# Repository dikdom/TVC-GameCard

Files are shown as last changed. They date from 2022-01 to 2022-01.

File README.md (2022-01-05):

# TVC-GameCard
Egy IO bővítőkártya a Videoton TV Computerhez, melyen 2 extra joy port és egy SN76489 hangchip található. Ez a kártya a TVC játékos lehetőségeit
bővíti a jobb zenei lehetőségeivel és a 4 játékos üzemmóddal.

Ez a repo a méltán nagysikerű Videoton TV Computerhez készített TVC-GameCard IO kártya leírását és újragyártásához szükséges file-okat tartalmazza.
A kártya 2 extra joy portot, egy SN76489 hangchipet (+3 hangcsatorna +1 zajcsatorna) és 4 extra játékot tartalmaz. Bekapcsoláskor a felhasználó
választhat a játékok közül, de akár tovább is léphet a sima, sztenderd BASIC bekapcsolási képernyőre (...khm... felé, mert ha van több IO kártya
is bedugva a gépbe, akkor simán lehet, hogy a következő kártya fogja megfogni a boot folyamatát..)

Könyvtárstruktúra:
- `doc` dokumentumok a kártyáról
- `src`
  - `menu`
    a boot menü forráskódja, ami az ASM80.com oldalon található IDE-vel készült
  - `gal`
    a GAL20V8B chip kódjainak a forrásai, amit a WinCUPL programmal lehet lefordítani
  - `hw` kapcsolási rajz és board layout EagleCAD formátumban
  - `tvc4snake` a TVC4Snake játék forrása
- `bin`
  minden, ami egy kártya elkészítéséhez szükséges: a gerber file csomagok (TH és SMD konfiguráció, az SMD -hez a gyártási file-ok is a JLC felé), 
  a GAL-ok lefordított .jed file-jai és a EPROM-ba írható bináris, ami a lefordított  boot menüt és a játékokat is tartalmazza

MIT License: minden használható/módosítható, de forrást tessék feltüntetni

An IO expander card for Videoton TV Computer having +2 joy port and an SN76489 sound chip.

MIT License: you can use anything as you want but please, link the source in your project

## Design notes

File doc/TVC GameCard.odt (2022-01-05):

TVC GameCard

Felhasználóknak és programozóknak

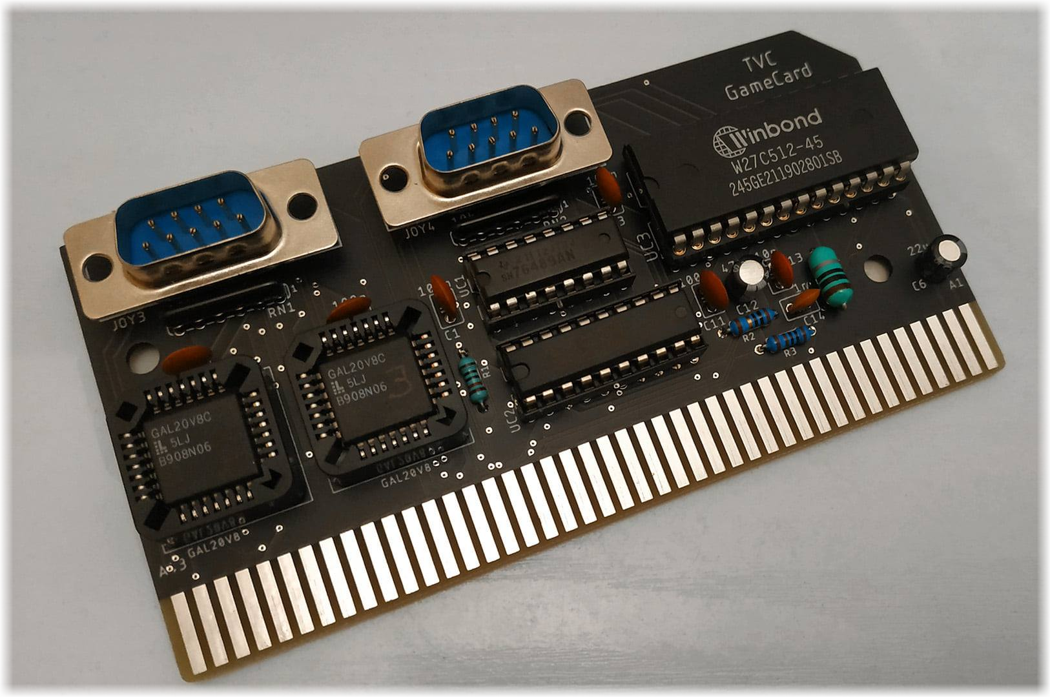
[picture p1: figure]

TVC GameCard - bevezető

A TVC-GameCard a Videoton TV Computer-hez készült IO bővítőkártya. Használatával lehetőségünk van 4 játékos üzemmódú, 3 csatornás zenével rendelkező játékokkal játszani a TVC-n (aminek ugye alapból 2 joy portja van, 1 csatornás hangképzése és alapból nem indul el játék róla).

Megj.:a felhasználók nagyobb részének az SMD alkatrészekkel szerelt kártya jutott, ami nem pont így néz ki, mint ami a fotón látható, de funkciójában a két kiépítés semmiben nem különbözik egymástól.

Használata

Bekapcsolás

A GameCard -ot mindig kikapcsolt TVC -be dugjuk be. Ha lehet, akkor joy kábeleket is a TVC kikapcsolt állapotában csatlakoztassuk. Ha nem lehet, akkor viszont járjunk el kellő körültekintéssel csatlakoztatáskor!

A gép bekapcsolásakor egy egyszerű bootmenü jelenik meg, ahol láthatjuk a játékprogramok szerzőit, a boot menü verzióját és a lehetőségeinket, hogy hogyan haladhatunk tovább.

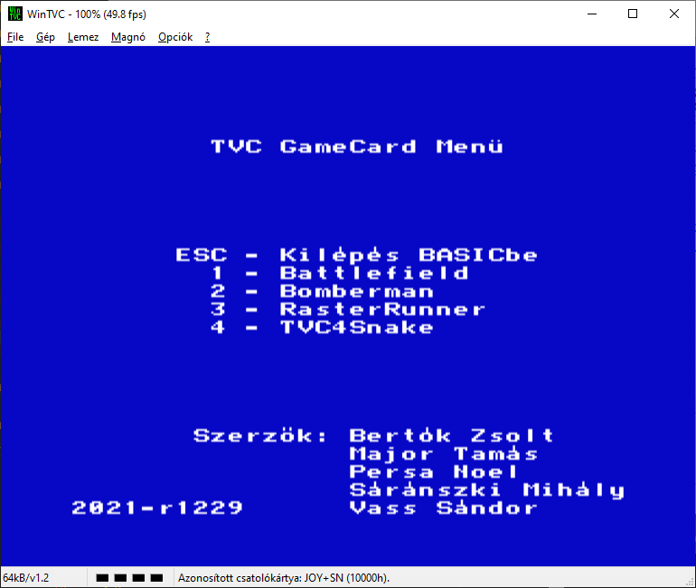
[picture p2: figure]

(WinTVC, v1.3)

Opciók

ESC

A GameCard ilyenkor kilép a menüből és visszaadja a vezérlést a TVC -nek. A TVC befejezi a csatlakoztatott IO kártyák (ha van) INIT rutinjainak a hívásait és aszerint halad tovább. Ha nincs más kártya csatlakoztatva a gépbe, akkor a TVC a szivárványos boot screen-en keresztül eljut a BASIC promptig. Fontos tudni, hogy a GameCard funkciói ekkor is elérhetőek maradnak: az ilyenkor betöltött programok is elérik a +2 joy portot és tudják használni a kártyán található SN76489 hangchipet.

Az EPROM tartalmát is, csak hát azzal ugye nem biztos, hogy sokra mennek…

1-4

A fenti számok egyikével választhatjuk ki, hogy melyik játékkal szeretnénk játszani. Mind a 4 játék támogatja a 4 játékos üzemmódot és egytől egyik kiváló játékokról van szó!!

- A BattleField egy tankos, lövöldözős játék. Lehetőség van négyen, vagy kevesebben és akár gépi ellenfelek ellen is játszani. Többféle pálya közül választhatunk, a repülő a bombáival meg tud viccelni.
- A Bomberman a hagyományos bomberman játék. A kártyán található v1.1 -es változat még nem tartalmaz gépi ellenfeleket viszont többféle játékmenet és többféle pálya közül lehet választani.
- A Rasterrunner egy tron-szerű játék, szintén lehet 4-en vagy kevesebben, akár gépi ellenfelek ellen lehet benne játszani.
- A TVC4Snake játékot szerénységem követte el. 1-4 szereplős, sima, egyszerű kukacjáték annyi csavarral, hogy alkalmanként egy gépi ellenfél (ellenkukac) nehezíti meg a pontszerzést. A játék különlegessége, hogy C nyelven íródott.

RESET

A kártya induláskor átkonfigurálja a reset állapotot, így ha játék közben reset gombot nyomunk, akkor a gép ‘hideg’ resetet hajt végre és a menübe térünk vissza.

Erre azért van szükség, mert amikor a kártyáról indulnak a programok, a BASIC init nem hajtódik végre ezért veszélyes lenne BASIC-be ‘visszatérni’ a játékokból.

Programozóknak

ID string

A kártya az ‘JOY+SN’ ID stringgel rendelkezik, azaz az IO kártyáknak lefoglalt megfelelő RAM területen (0x40-0x6F, 0x70-0x9F, …) a

0x06 0x46 0x4F 0x59 0x2B 0x53 0x4E

byte-ok sorakoznak, amennyiben a TVC érzékelte a kártyát. Egy program így tudja megtalálni, hogy melyik slotban van a TVC-GameCard, amivel együtt az is megvan, hogy a GameCard melyik IO tartományt használja (rendre: 0x10-0x1F, 0x20-0x2F, …)

Control IO regiszter

Az IO kártya a saját foglalatának megfelelő IO tartományt az előző fejezetben megtaláltuk. Miért fontos ez? Azért, mert a kártya ezen IO tartományon belüli portokon keresztül vezérelhető. A +0x0F címen (azaz 0x1F vagy 0x2F, stb, használt slottól függően) a kártya control regisztere található. Ez a regiszter csak írható, olvasásra nincs definiált válasz.

ROM select

A control regiszter alsó 3 bitje (b2-b0) jelöli ki, hogy melyik 8kB-os tartomány legyen látható az EPROM-ból az IO kártyáknak fenntartott EXROM memóriaterületen a TVC számára. Ezt az alsó 3 bitet tipikusan a menü használja, amikor az EPROM-ból másolja be a kiválasztott programot a TVC RAM területére (azaz program indításakor).

SND enable

A control regiszter 4. bitje (b3) engedélyezi, vagy éppenséggel tiltja a hangchipet. A háttérben a hangchiphez tartozó clock jelet tiltja a kártya, így amíg a hangchip le van tiltva, utasítások sem küldhetőek rá (hangerő, első hangjegy beállítása, stb…).

Kezdetek

Induláskor és reset hatására a control regiszterbe a xxxx0111 érték íródik, azaz a 64kB-os EPROMból a legfelső 8kB-nyi terület lapozódik be a TVC EXROM területére (az EEPROM-on a $E000-$FFFF terület a TVC $C000-$DFFF területére). A TVC-GameCard -on itt található a boot menü program.

SN regiszter

Az SN chip regisztere a +0x00 címen található. Ez a regiszter is csak írható. Fontos tudni, hogy az TVC GameCard -on az SN chip a TVC órajelét kapja (3,125MHz), mint alapórajel, azaz ez nem egyezik meg a Multichip soundcard -on található SN chip órajelével (3,579MHz). A két órajel között kb. egy ⅞ -os szorzó van (MC clock * 7 / 8 = GC clock)

Joystick portok

A két extra joystick állapotait a +0x02 és a +0x03 portok olvasásával szerezhetjük meg. A bitek alacsonyaktívak (azaz a bit 0 értéke jelenti az aktivitást) és a következő hozzárendeléssel rendelkeznek:

- bit0: fölfelé irány
- bit1: lefelé irány
- bit2: balra irány
- bit3: jobbra irány
- bit4: tűzgomb
- b5-b7: nem definiált

A két extra joy port nem rendelkezik a TVC joystick-ok második tűzgombjával, viszont autofire-barát, azaz a +5V ki van vezetve.

Például egy

- alaphelyzetben lévő joy port a következő értéket kell visszaadja:

beolvasott_érték AND b00011111 => b00011111

- egy tűzgombot lenyomott joy esetében:

beolvasott_érték AND b00011111 => b00001111

- egy fölfelé és jobbra, átlósan húzott joy esetében:

beolvasott_érték AND b00011111 => b00010110

Gyakorlatilag ennyi. Aki ezt tudja, innentől tudja programozni a GameCard -ot, tud rá játékot is írni.

Források

Minden más megtalálható a kártya github lapján: https://github.com/dikdom/TVC-GameCard

Köszönet

Köszönettel tartozom a programozóknak, akiknek a játékai nélkül nem jöhetett volna létre ez a projekt. ABC rendben:

- Bertók Zsolt
- Major Tamás
- Persa Noel
- Sáránszki Mihály

Nagyon szép, nagyon jó ez a kártya, viszont a szuper játékok nélkül fabatkát sem ér.

Sáránszki Mihálynak köszönet jár ismét a remek cÍmlap fotóért.

És köszönettel tartozom a családomnak is, különösképpen a feleségemnek, aki eltűri, hogy el-eltűnök a családi életből 1-2, néha több órára az ilyen projektjeim végett…

Vass Sándor

Budapest, 2022, Január 5.

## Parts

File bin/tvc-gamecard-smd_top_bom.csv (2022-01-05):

Comment | Designator | Footprint | LCSC Part #
1k | R3 | R0805 | C17513
1n | C14 | C0805 | C46653
10R | R2 | R0805 | C17415
10k | R1 | R0805 | C17414
10n | C13 | C0805 | C1710
10uH | L1 | L1210 | C1051
22u | C6 | C0805 | C45783
47u | C12 | C1206 | C96123
74HCT574D | UC2 | SO20W
100n | C1 C3 C4 C5 C11 | C0805 | C49678
CTS742C083 | RN1 RN2 RN3 | 0603_x4 | C29718

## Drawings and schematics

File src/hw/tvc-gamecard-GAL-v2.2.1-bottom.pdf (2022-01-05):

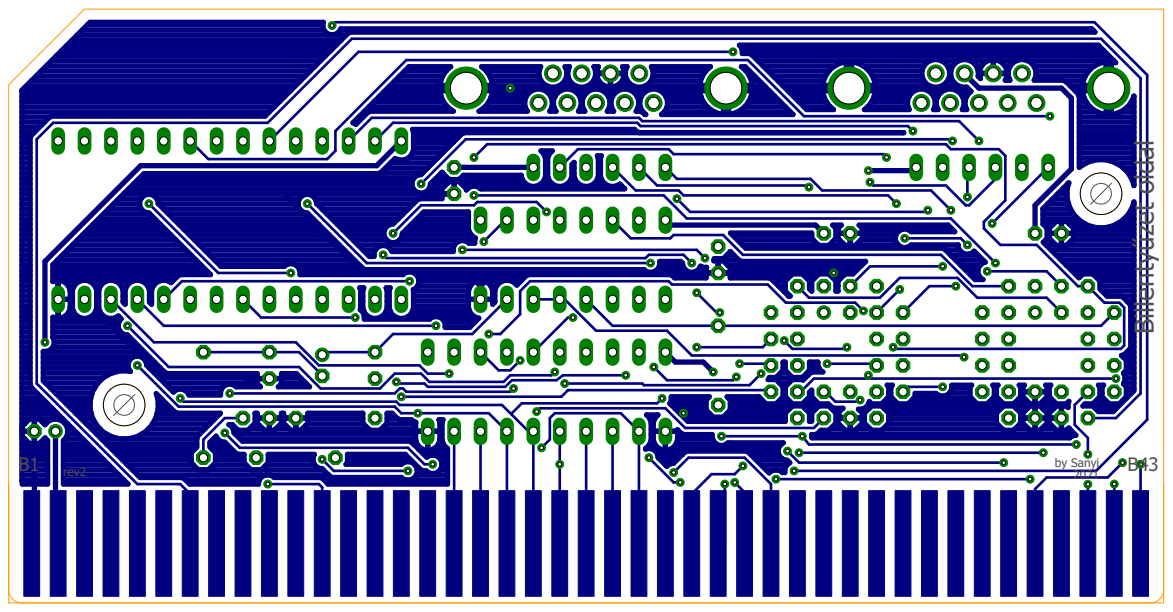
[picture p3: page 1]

Billentyűzet oldal by Sanyi 2021 B1 rev2 B43

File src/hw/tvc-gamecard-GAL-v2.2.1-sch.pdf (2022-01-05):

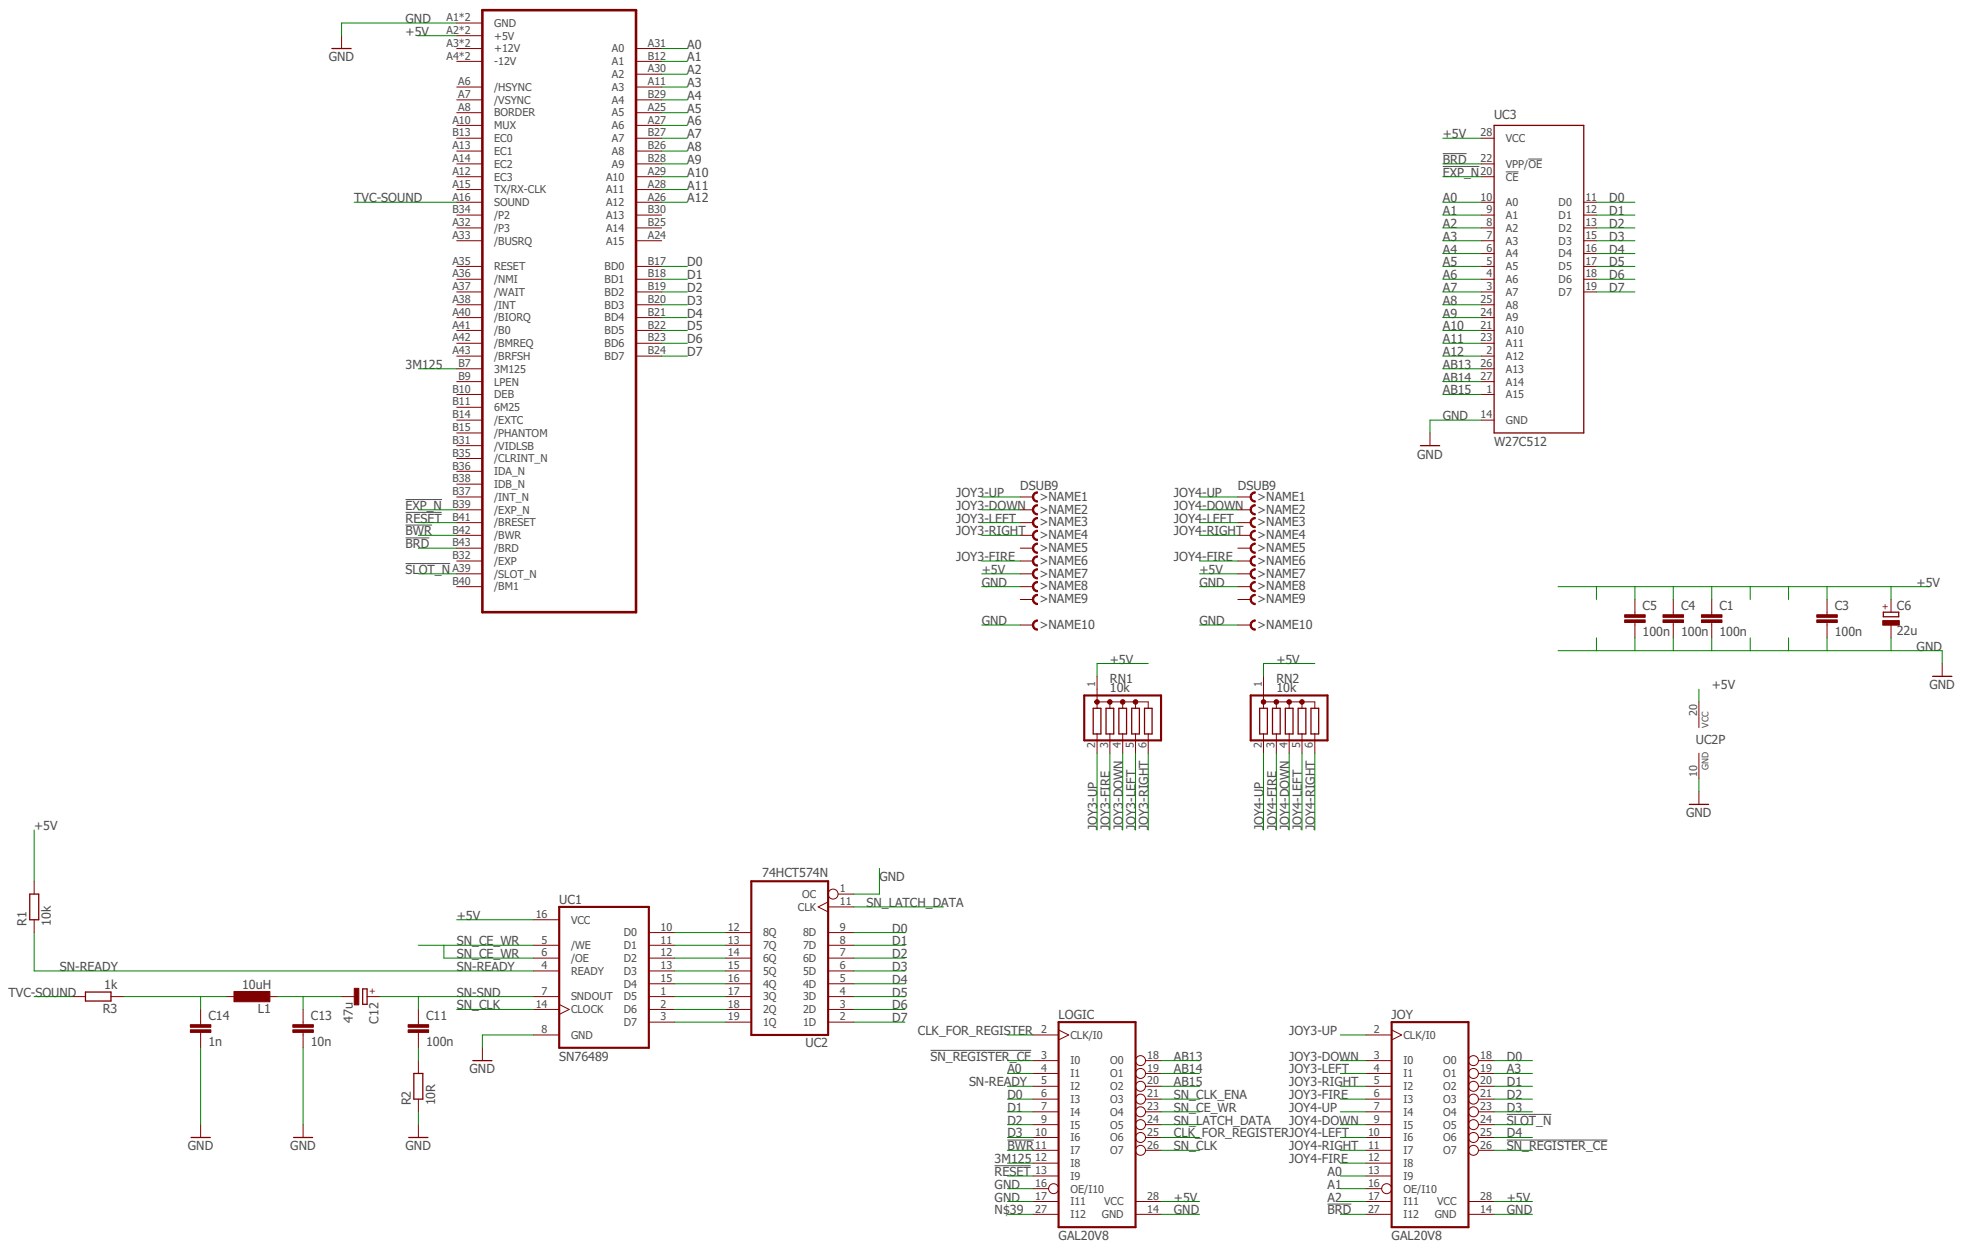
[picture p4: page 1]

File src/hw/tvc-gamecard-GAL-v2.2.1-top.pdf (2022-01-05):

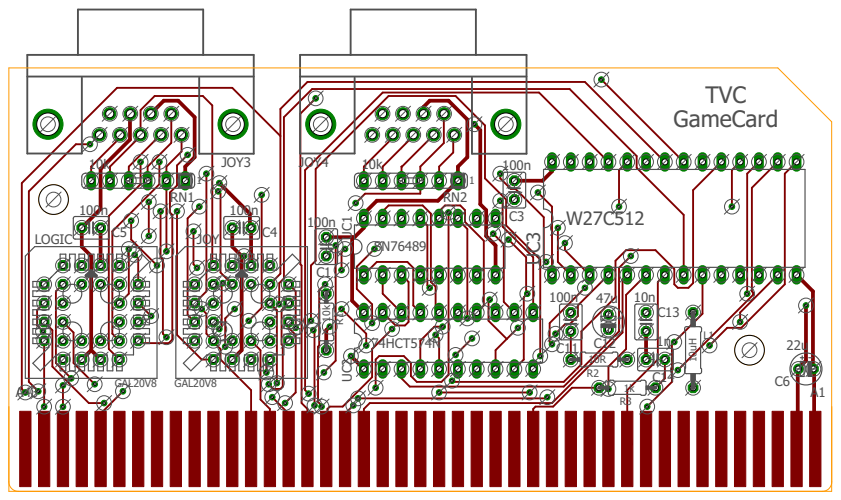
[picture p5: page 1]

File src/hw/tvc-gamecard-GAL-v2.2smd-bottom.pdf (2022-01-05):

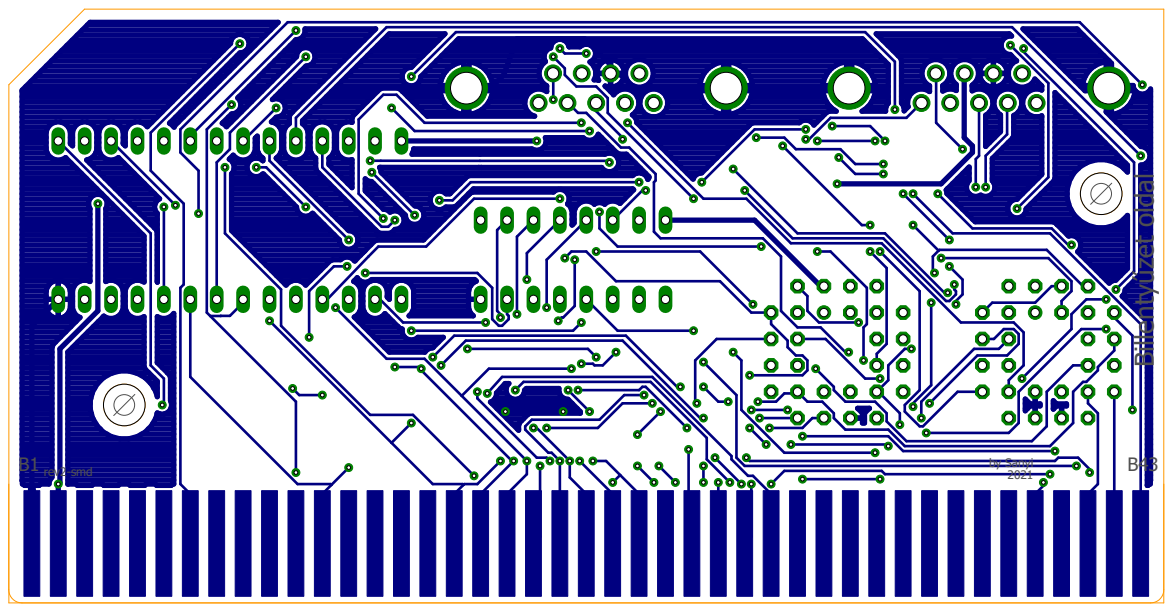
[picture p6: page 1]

Billentyűzet oldal by Sanyi 2021 B1 rev2-smd B43

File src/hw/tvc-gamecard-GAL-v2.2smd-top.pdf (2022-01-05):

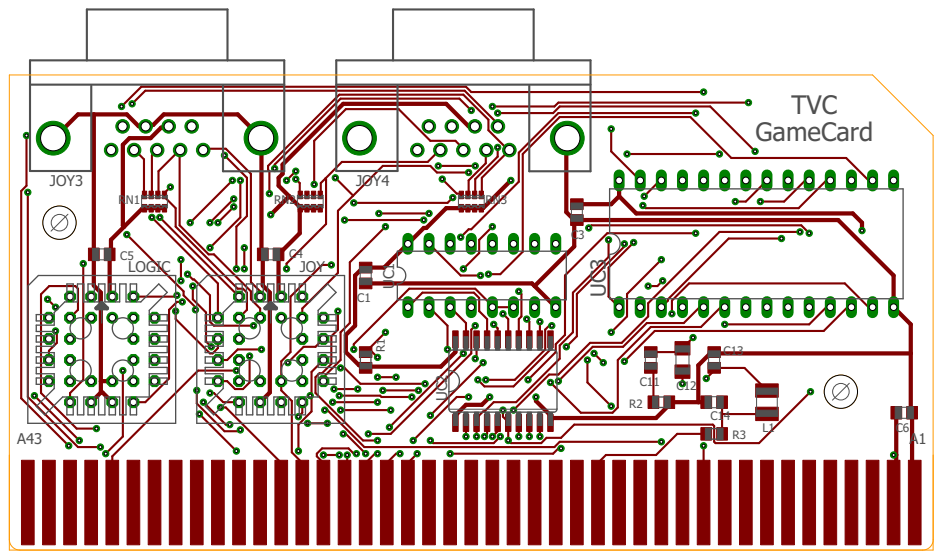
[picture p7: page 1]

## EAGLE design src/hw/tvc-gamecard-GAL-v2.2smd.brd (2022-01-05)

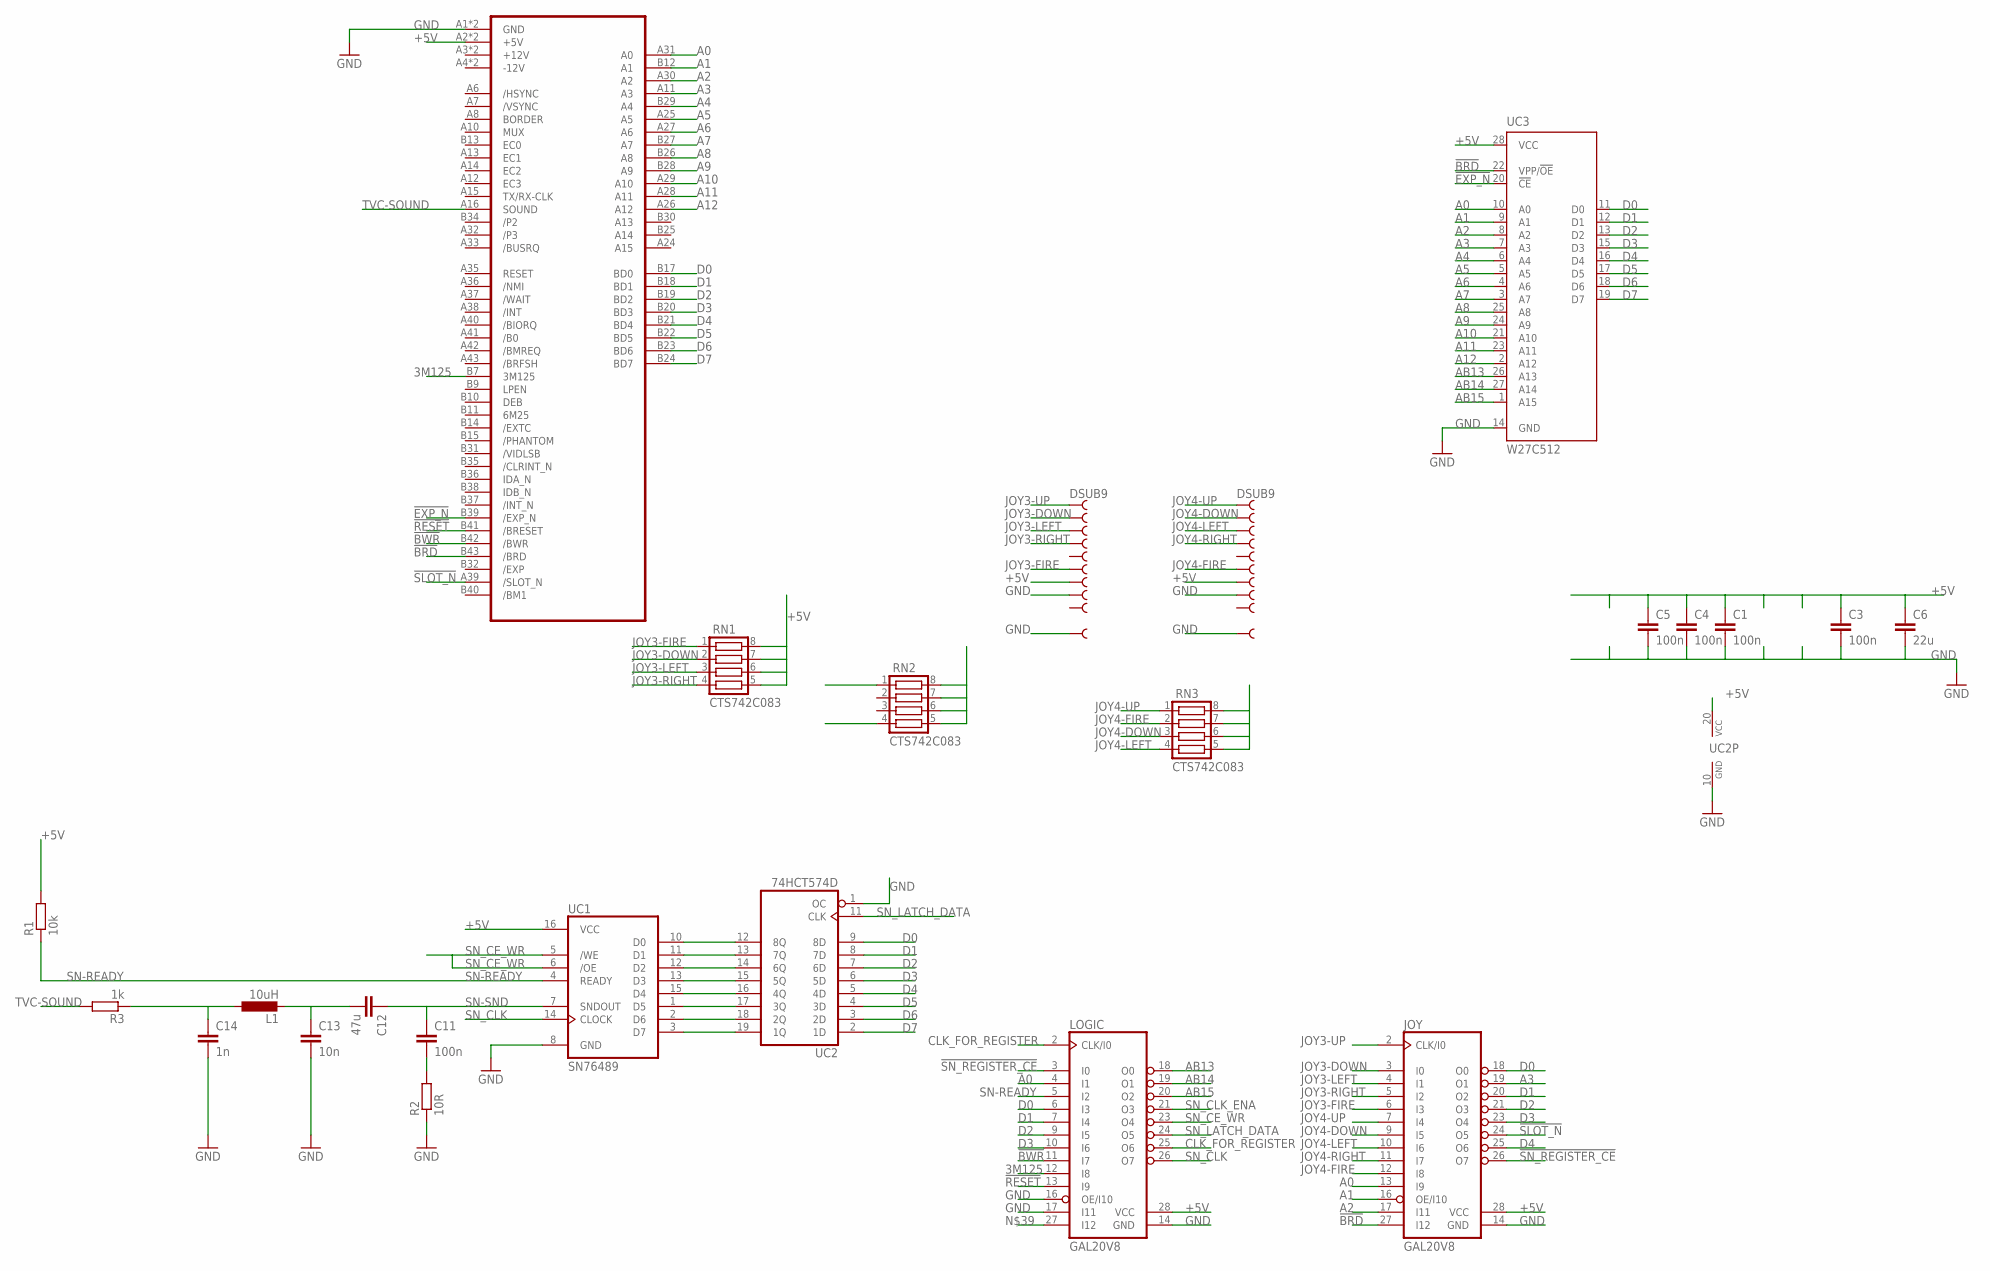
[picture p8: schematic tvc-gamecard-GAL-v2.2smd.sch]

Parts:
C1, C3, C4, C5, C11: 100n; C0805
C6: 22u; C0805
C12: 47u; C1206
C13: 10n; C0805
C14: 1n; C0805
CON1: TVC-EXP-HBA-COMMON; TVC-EXP-EDGE
JOY: GAL20V8; PLCC-S28-SOCKET
JOY3, JOY4: DSUB9; H3M09RA
L1: 10uH; L1210
LOGIC: GAL20V8; PLCC-S28-SOCKET
R1: 10k; R0805
R2: 10R; R0805
R3: 1k; R0805
RN1, RN2, RN3: CTS742C083
UC1: SN76489; DIL16
UC2: 74HCT574D; SO20W
UC3: W27C512; DIL28-6

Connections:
3M125: CON1.B7 (3M125), LOGIC.12 (I8)
!BRD: CON1.B43 (/BRD), JOY.27 (I12), UC3.22 (VPP/!OE)
!BWR: CON1.B42 (/BWR), LOGIC.11 (I7)
!EXP_N: CON1.B39 (/EXP_N), UC3.20 (!CE)
!RESET: CON1.B41 (/BRESET), LOGIC.13 (I9)
!SLOT_N: CON1.A39 (/SLOT_N), JOY.24 (O5)
!SN_REGISTER_CE: JOY.26 (O7), LOGIC.3 (I0)
+5V: C1.1, C3.1, C4.1, C5.1, C6.1, CON1.A2 (+5V), CON1.B2 (+5V), JOY.28 (VCC), JOY3.7, JOY4.7, LOGIC.28 (VCC), R1.2, RN1.5, RN1.6, RN1.7, RN1.8, RN2.5, RN2.6, RN2.7, RN2.8, RN3.5, RN3.6, RN3.7, RN3.8, UC1.16 (VCC), UC2.20 (VCC), UC3.28 (VCC)
A0: CON1.A31 (A0), JOY.13 (I9), LOGIC.4 (I1), UC3.10 (A0)
A1: CON1.B12 (A1), JOY.16 (OE/I10), UC3.9 (A1)
A2: CON1.A30 (A2), JOY.17 (I11), UC3.8 (A2)
A3: CON1.A11 (A3), JOY.19 (O1), UC3.7 (A3)
A4: CON1.B29 (A4), UC3.6 (A4)
A5: CON1.A25 (A5), UC3.5 (A5)
A6: CON1.A27 (A6), UC3.4 (A6)
A7: CON1.B27 (A7), UC3.3 (A7)
A8: CON1.B26 (A8), UC3.25 (A8)
A9: CON1.B28 (A9), UC3.24 (A9)
A10: CON1.A29 (A10), UC3.21 (A10)
A11: CON1.A28 (A11), UC3.23 (A11)
A12: CON1.A26 (A12), UC3.2 (A12)
AB13: LOGIC.18 (O0), UC3.26 (A13)
AB14: LOGIC.19 (O1), UC3.27 (A14)
AB15: LOGIC.20 (O2), UC3.1 (A15)
CLK_FOR_REGISTER: LOGIC.2 (CLK/I0), LOGIC.25 (O6)
D0: CON1.B17 (BD0), JOY.18 (O0), LOGIC.6 (I3), UC2.9 (8D), UC3.11 (D0)
D1: CON1.B18 (BD1), JOY.20 (O2), LOGIC.7 (I4), UC2.8 (7D), UC3.12 (D1)
D2: CON1.B19 (BD2), JOY.21 (O3), LOGIC.9 (I5), UC2.7 (6D), UC3.13 (D2)
D3: CON1.B20 (BD3), JOY.23 (O4), LOGIC.10 (I6), UC2.6 (5D), UC3.15 (D3)
D4: CON1.B21 (BD4), JOY.25 (O6), UC2.5 (4D), UC3.16 (D4)
D5: CON1.B22 (BD5), UC2.4 (3D), UC3.17 (D5)
D6: CON1.B23 (BD6), UC2.3 (2D), UC3.18 (D6)
D7: CON1.B24 (BD7), UC2.2 (1D), UC3.19 (D7)
GND: C1.2, C3.2, C4.2, C5.2, C6.2, C13.2, C14.2, CON1.A1 (GND), CON1.B1 (GND), JOY.14 (GND), JOY3.8, JOY3.P$1 (S), JOY3.P$2 (S), JOY4.8, JOY4.P$1 (S), JOY4.P$2 (S), LOGIC.14 (GND), LOGIC.16 (OE/I10), LOGIC.17 (I11), R2.1, UC1.8 (GND), UC2.1 (OC), UC2.10 (GND), UC3.14 (GND)
JOY3-DOWN: JOY.3 (I0), JOY3.2, RN1.2
JOY3-FIRE: JOY.6 (I3), JOY3.6, RN1.1
JOY3-LEFT: JOY.4 (I1), JOY3.3, RN1.3
JOY3-RIGHT: JOY.5 (I2), JOY3.4, RN1.4
JOY3-UP: JOY.2 (CLK/I0), JOY3.1, RN2.4
JOY4-DOWN: JOY.9 (I5), JOY4.2, RN3.3
JOY4-FIRE: JOY.12 (I8), JOY4.6, RN3.2
JOY4-LEFT: JOY.10 (I6), JOY4.3, RN3.4
JOY4-RIGHT: JOY.11 (I7), JOY4.4, RN2.1
JOY4-UP: JOY.7 (I4), JOY4.1, RN3.1
unnamed: C11.2, R2.2
unnamed: C12.2, C13.1, L1.2
unnamed: C14.1, L1.1, R3.1
unnamed: UC1.10 (D0), UC2.12 (8Q)
unnamed: UC1.11 (D1), UC2.13 (7Q)
unnamed: UC1.12 (D2), UC2.14 (6Q)
unnamed: UC1.13 (D3), UC2.15 (5Q)
unnamed: UC1.15 (D4), UC2.16 (4Q)
unnamed: UC1.1 (D5), UC2.17 (3Q)
unnamed: UC1.2 (D6), UC2.18 (2Q)
unnamed: UC1.3 (D7), UC2.19 (1Q)
SN-READY: LOGIC.5 (I2), R1.1, UC1.4 (READY)
SN-SND: C11.1, C12.1, UC1.7 (SNDOUT)
SN_CE_WR: LOGIC.23 (O4), UC1.5 (/WE), UC1.6 (/OE)
SN_CLK: LOGIC.26 (O7), UC1.14 (CLOCK)
SN_CLK_ENA: LOGIC.21 (O3)
SN_LATCH_DATA: LOGIC.24 (O5), UC2.11 (CLK)
TVC-SOUND: CON1.A16 (SOUND), R3.2

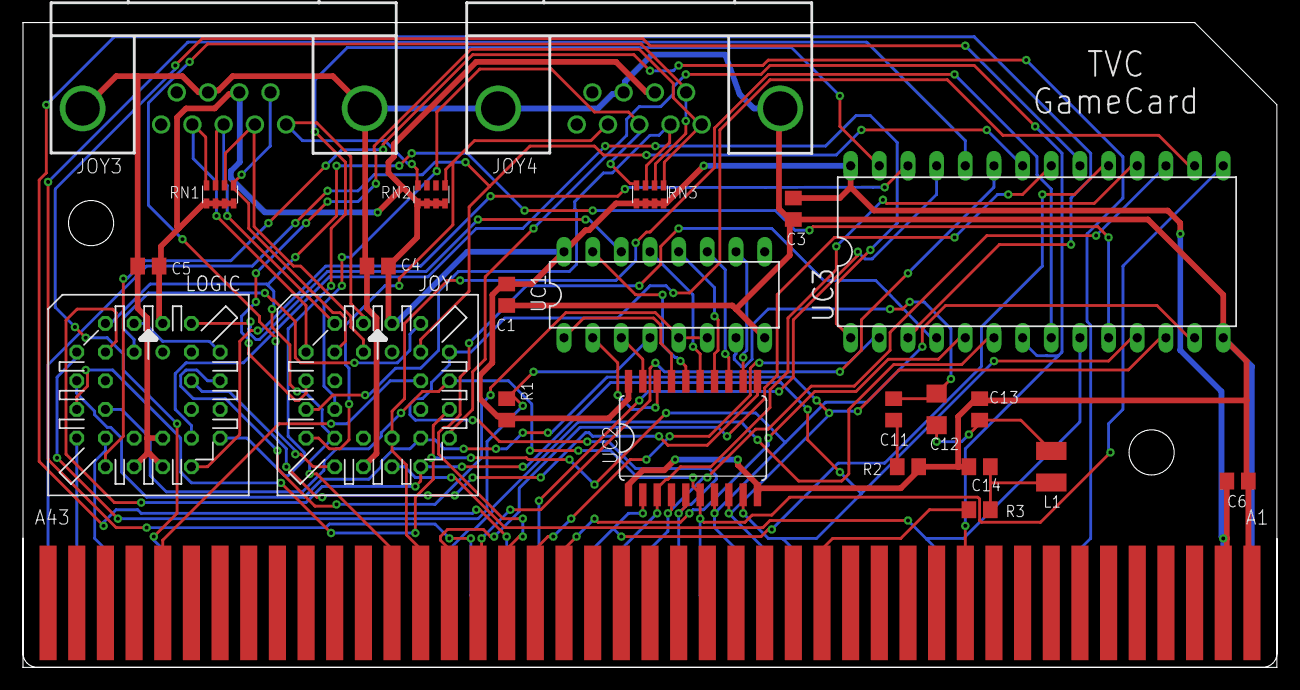
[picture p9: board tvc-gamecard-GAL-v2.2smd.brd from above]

Board: 2 copper layers, 111.1 x 57.1 mm, 24 parts (0 on the bottom side), 61 nets.
